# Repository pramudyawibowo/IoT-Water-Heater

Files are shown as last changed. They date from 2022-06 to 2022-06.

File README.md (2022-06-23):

## Project IoT : 
# Pemanas Air Otomatis dengan Monitoring Suhu dan Kelembapan Udara

## Anggota Kelompok 
| No | Nama | NIM |
|:--:|:---:|:---:|
|  1 | Abdur Rozak Junaidi | 1941720094 |
|  2 | Dwi Nur Oktaviani | 1941720239 |
|  3 | Pramudya Wibowo | 1941720054 |

## Pengkabelan
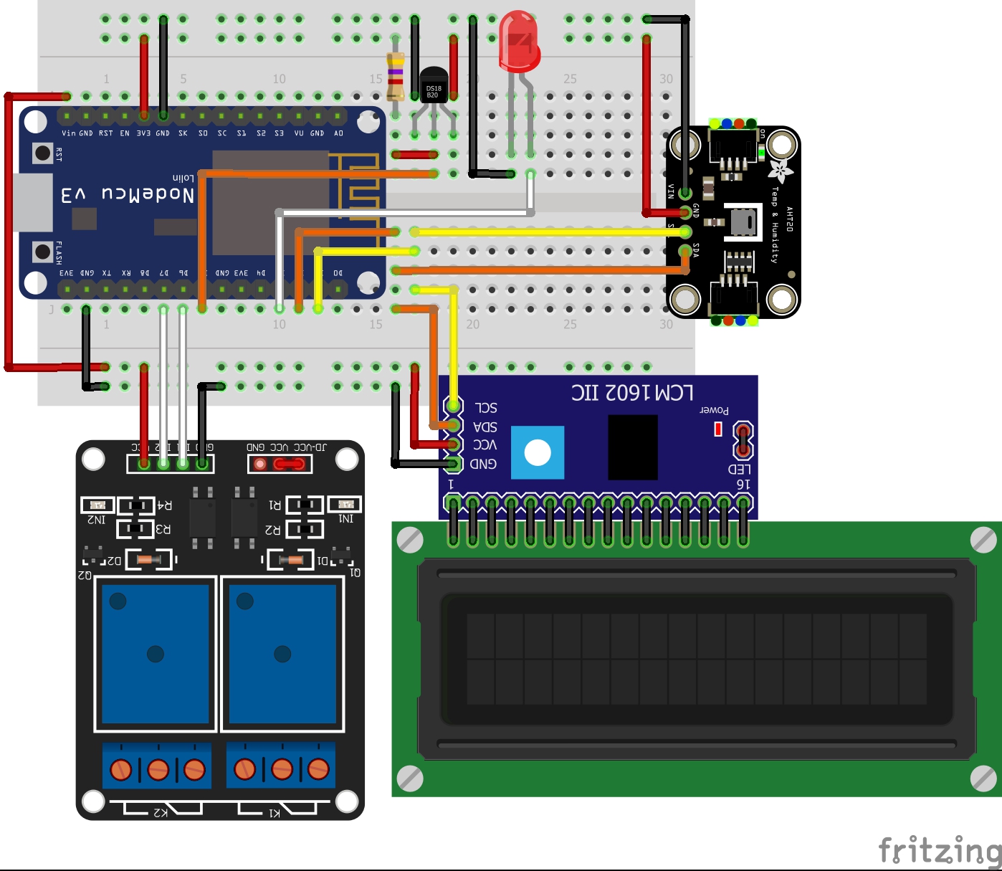
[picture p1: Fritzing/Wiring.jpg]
Pengkabelan Fritzing
 

## Langkah Penggunaan Kode Program
* Atur pengkabelan seperti pada contoh diatas
* Ubah SSID dan Password dengan SSID dan Password dari Wifi yang digunakan.
* Atur alamat MQTT Broker yang digunakan.
* Atur pin-pin dari perangkat apabila diperlukan.
* Upload program, tunggu perangkat booting hingga LCD menunjukkan tampilan monitoring suhu.
* Akses node-red dashboard dengan alamat http://168.138.175.53:1880/ui
* Demo project dan uji coba dapat dilihat melalui link berikut https://youtu.be/ZZKoxPK8TpI

Demo Project IoT (https://youtu.be/ZZKoxPK8TpI "Demo Project IoT")

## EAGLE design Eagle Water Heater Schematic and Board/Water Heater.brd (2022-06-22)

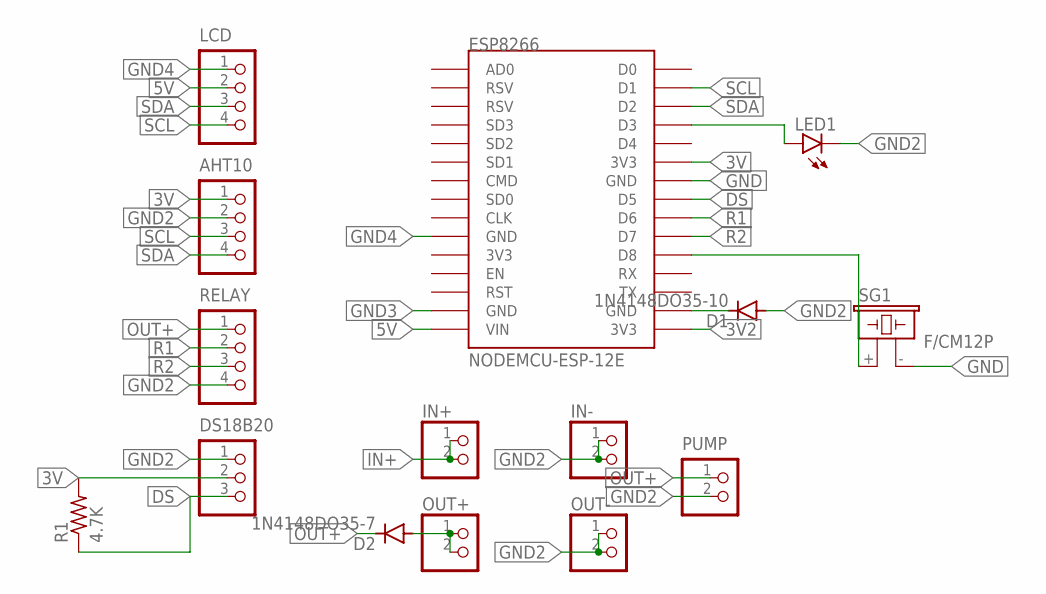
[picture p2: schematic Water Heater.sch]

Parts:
AHT10: B4B-XH-A
D1: 1N4148DO35-10; DO35-10
D2: 1N4148DO35-7; DO35-7
DS18B20: B3B-XH-A
ESP8266: NODEMCU-ESP-12E
IN+: PINHD-1X2; 1X02
IN-: PINHD-1X2; 1X02
LCD: B4B-XH-A
LED1: LED3MM
OUT+: PINHD-1X2; 1X02
OUT-: PINHD-1X2; 1X02
PUMP: B2B-XH-A
R1: 4.7K; 0204/7
RELAY: B4B-XH-A
SG1: F/CM12P

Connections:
3V: AHT10.1, DS18B20.2, ESP8266.3V3@1 (3V3), R1.2
3V2: ESP8266.3V3@2 (3V3)
5V: ESP8266.VIN, LCD.2
DS: DS18B20.3, ESP8266.D5, R1.1
GND: ESP8266.GND@2 (GND), SG1.- (2)
GND2: AHT10.2, D1.A, DS18B20.1, IN-.1, IN-.2, LED1.K (C), OUT-.1, OUT-.2, PUMP.2, RELAY.4
GND3: ESP8266.GND@1 (GND)
GND4: ESP8266.GND@0 (GND), LCD.1
IN+: IN+.1, IN+.2
unnamed: ESP8266.D3, LED1.A
unnamed: ESP8266.D8, SG1.+ (1)
unnamed: D1.C, ESP8266.GND@3 (GND)
unnamed: D2.A, OUT+.1, OUT+.2
OUT+: D2.C, PUMP.1, RELAY.1
R1: ESP8266.D6, RELAY.2
R2: ESP8266.D7, RELAY.3
SCL: AHT10.3, ESP8266.D1, LCD.4
SDA: AHT10.4, ESP8266.D2, LCD.3

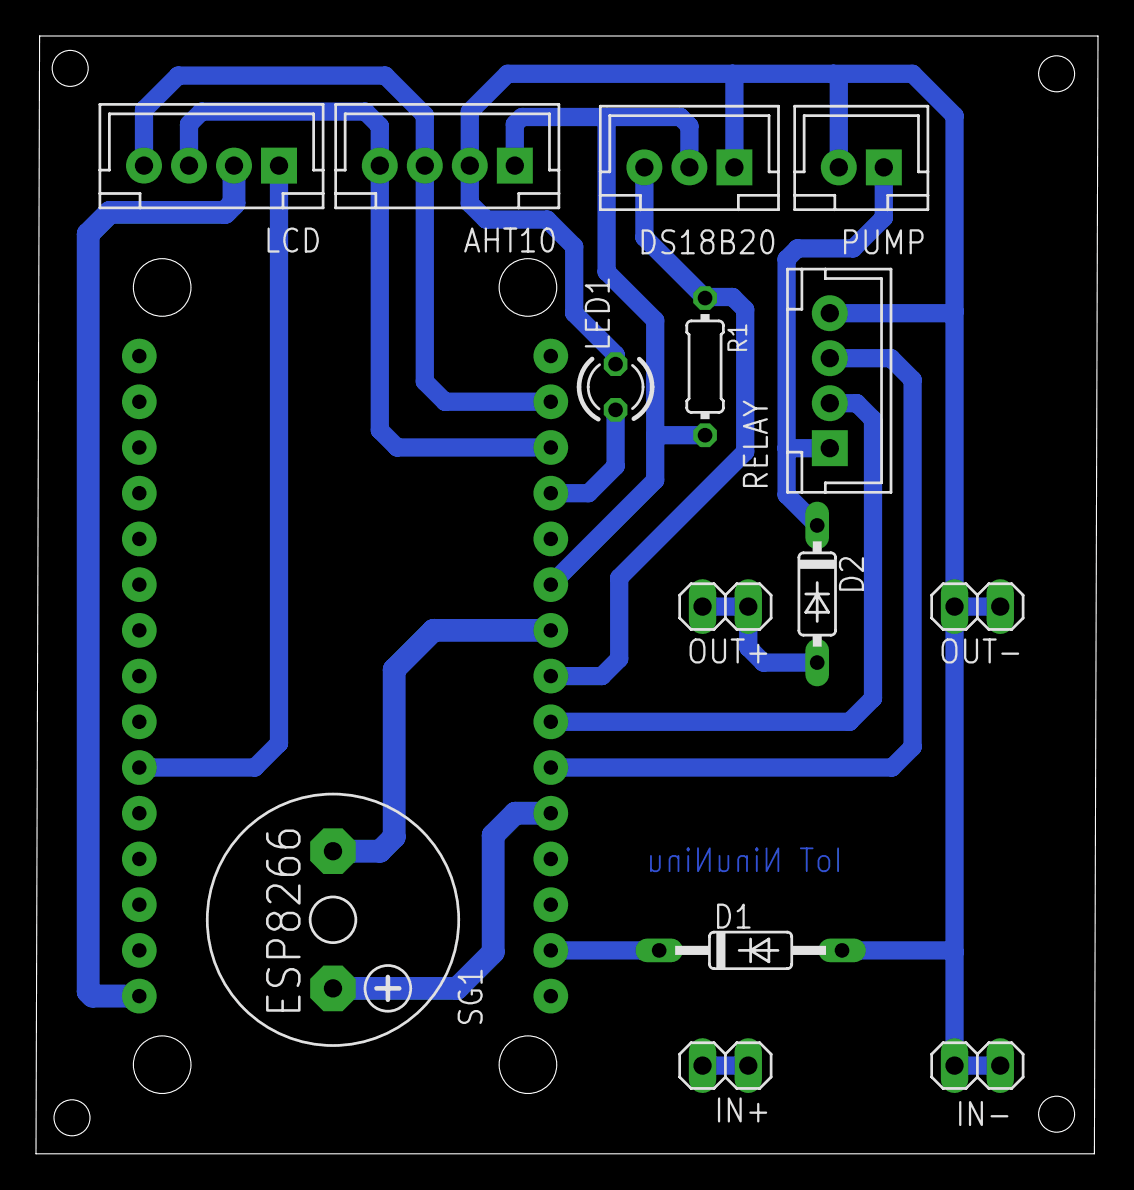
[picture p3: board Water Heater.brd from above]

Board: 2 copper layers, 59.0 x 62.1 mm, 15 parts (0 on the bottom side), 16 nets.

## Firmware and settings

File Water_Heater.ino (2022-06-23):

#include <Arduino.h>
#include <ESP8266WiFi.h>
#include <PubSubClient.h>
#include <Adafruit_AHT10.h>
#include <LiquidCrystal_I2C.h>
#include <OneWire.h>
#include <DallasTemperature.h>
#include <EEPROM.h>

#define pinDS     D5
#define pinPompa  D7
#define pinHeater D6
#define pinLED    D3
#define pinBuzzer D8

const char *ssid = "SSID";
const char *password = "password";
const char *mqtt_server = "138.2.87.224";
String newHostname = "water-heater";
WiFiClient espClient;
PubSubClient client(espClient);
Adafruit_AHT10 aht;
LiquidCrystal_I2C lcd(0x27, 16, 2);
OneWire DS18B20(pinDS);
DallasTemperature ds(&DS18B20);
char buff[33];
unsigned long previousSend = 0, previousSensor = 0, previousPompa = 0, previousBuzzer = 0;
byte heaterChar[] = {0x0E, 0x0A, 0x0A, 0x0E, 0x1F, 0x1F, 0x1F, 0x0E};
byte powerChar[] = {0x00, 0x04, 0x04, 0x0E, 0x15, 0x11, 0x11, 0x0E};

float suhuUdara, kelembapanUdara, suhuUdaraMax, suhuAir, suhuAirMin;
sensors_event_t humidity, temp;
bool heater = false, pompa = false, buzzer = false;
String heaterStatus = "false";
int seconds = 1, buzzerCount = 0;

void initInterface() {
  lcd.init();
  lcd.backlight();
  lcd.createChar(1, powerChar);
  lcd.createChar(2, heaterChar);
}

void printLcd(int col, int row, String text) {
  lcd.setCursor(col, row);
  lcd.print(text);
}

void initDevices() {
  pinMode(pinLED, OUTPUT);
  pinMode(pinHeater, OUTPUT);
  pinMode(pinPompa, OUTPUT);
  pinMode(pinBuzzer, OUTPUT);
  digitalWrite(pinLED, LOW);
  digitalWrite(pinHeater, HIGH);
  digitalWrite(pinPompa, HIGH);
  aht.begin();
  ds.begin();
}

void readSensors() {
  unsigned long currentSensor = millis();
  if (currentSensor - previousSensor >= 500) {
    previousSensor = currentSensor;
    aht.getEvent(&humidity, &temp);
    kelembapanUdara = humidity.relative_humidity;
    suhuUdara = temp.temperature;
    ds.setResolution(12);
    ds.requestTemperatures();
    suhuAir = ds.getTempCByIndex(0);
  }
}

void initWifi() {
  WiFi.mode(WIFI_STA);
  WiFi.hostname(newHostname.c_str());
  WiFi.begin(ssid, password);
  printLcd(0, 0, "   CONNECTING   ");
  while (WiFi.status() != WL_CONNECTED) {
    delay(250);
  }
  printLcd(0, 0, "   CONNECTED!   ");
  printLcd(0, 1, "IP:");
  printLcd(3, 1, WiFi.localIP().toString());
  delay(2000);
  lcd.clear();
}

void initMqtt() {
  client.setServer(mqtt_server, 1883);
  client.setCallback(callback);
}

void reconnect() {
  while (!client.connected()) {
    printLcd(0, 0, "Connecting MQTT ");
    delay(500);
    if (client.connect("WaterHeater")) {
      printLcd(0, 0, " MQTT Connected ");
      client.subscribe("heater/status");
      client.subscribe("heater/suhuHeater");
      client.subscribe("heater/saveHeater");
      client.subscribe("heater/suhuUdara");
      client.subscribe("heater/saveUdara");
      client.subscribe("pompa/status");
    } else {
      printLcd(0, 0, "MQTT Failed    ");
      printLcd(0, 1, String(client.state()));
    }
  }
  delay(500);
}

void callback(char* topic, byte* message, unsigned int length) {
  String messageTemp;
  for (int i = 0; i < length; i++) {
    messageTemp += (char)message[i];
  }
  if (String(topic) == "heater/status") {
    if (messageTemp == "false") {
      heater = false;
    } else if (messageTemp == "true") {
      heater = true;
    }
  }
  if (String(topic) == "heater/suhuHeater") {
    suhuAirMin = messageTemp.toFloat();
  }
  if (String(topic) == "heater/saveHeater") {
    if (messageTemp == "true") {
      printLcd(6, 1, " OK ");
      delay(500);
      EEPROM_writeFloat(0, suhuAirMin);
    }

  }
  if (String(topic) == "heater/suhuUdara") {
    suhuUdaraMax = messageTemp.toFloat();
  }
  if (String(topic) == "heater/saveUdara") {
    if (messageTemp == "true") {
      printLcd(12, 1, " OK ");
      delay(500);
      EEPROM_writeFloat(4, suhuUdaraMax);
    }
  }
  if (String(topic) == "pompa/status") {
    if (messageTemp == "false") {
      pompa = false;
    } else if (messageTemp == "true") {
      pompa = true;
      seconds = 1;
    }
  }
}

void readVariables() {
  EEPROM.begin(8);
  suhuAirMin = EEPROM_readFloat(0);
  suhuUdaraMax = EEPROM_readFloat(4);
}


void setup() {
  // put your setup code here, to run once:
  readVariables();
  initInterface();
  initDevices();
  initWifi();
  initMqtt();
  lcd.clear();
}

void loop() {
  // put your main code here, to run repeatedly:
  if (!client.connected()) {
    reconnect();
    lcd.clear();
  }
  if (!client.loop()) {
    client.connect("WaterHeater");
  }

  readSensors();
  lcd.setCursor(5, 0); lcd.write(2);
  dtostrf(suhuAir, 2, 1, buff);
  printLcd(6, 0, buff);
  lcd.setCursor(10, 0); lcd.print(" *");
  dtostrf(suhuUdara, 2, 1, buff);
  printLcd(12, 0, buff);
  dtostrf(suhuAirMin, 2, 1, buff);
  printLcd(6, 1, buff);
  dtostrf(suhuUdaraMax, 2, 1, buff);
  printLcd(12, 1, buff);

  lcd.setCursor(0, 0); lcd.write(1);
  if (heater) {
    printLcd(1, 0, "ON ");
    heaterStatus = "true";
    if (suhuUdara < suhuUdaraMax) {
      if (suhuAir < suhuAirMin - 2.0) {
        digitalWrite(pinHeater, LOW);
        digitalWrite(pinLED, HIGH);
      } else {
        if (suhuAir == suhuAirMin - 2.0) buzzer = true;
        digitalWrite(pinHeater, HIGH);
        digitalWrite(pinLED, LOW);
      }
    } else {
      digitalWrite(pinHeater, HIGH);
      digitalWrite(pinLED, LOW);
    }
  } else {
    printLcd(1, 0, "OFF");
    heaterStatus = "false";
    digitalWrite(pinHeater, HIGH);
    digitalWrite(pinLED, LOW);
  }

  if (pompa) {
    digitalWrite(pinPompa, LOW);
    unsigned long currentPompa = millis();
    if (seconds == 30) {
      pompa = false;
      seconds = 0;
    }
    if (currentPompa - previousPompa >= 1000) {
      previousPompa = currentPompa;
      seconds++;
      buzzer = true;
    }
  } else {
    digitalWrite(pinPompa, HIGH);
  }

  if (buzzer && buzzerCount < 3) {
    unsigned long currentBuzzer = millis();
    if (currentBuzzer - previousBuzzer >= 250) {
      previousBuzzer = currentBuzzer;
      tone(pinBuzzer, 1500, 200);
      buzzerCount++;
    }
  } else {
    buzzer = false;
    buzzerCount = 0;
  }

  unsigned long currentSend = millis();
  if (currentSend - previousSend >= 1000) {
    previousSend = currentSend;
    char tempSuhu[8];
    dtostrf(suhuUdara, 1, 2, tempSuhu);
    client.publish("udara/suhu", tempSuhu);

    char tempHumidity[8];
    dtostrf(kelembapanUdara, 1, 2, tempHumidity);
    client.publish("udara/kelembapan", tempHumidity);

    char tempHeater[8];
    dtostrf(suhuAir, 1, 2, tempHeater);
    client.publish("heater/suhu", tempHeater);

    char tempHeaterStatus[8];
    heaterStatus.toCharArray(tempHeaterStatus, 8);
    client.publish("heater/statusIn", tempHeaterStatus);
  }
}

void EEPROM_writeFloat(int ee, float value) {
  byte* p = (byte*)(void*)&value;
  for (int i = 0; i < 4; i++) {
    EEPROM.write(ee++, *p++);
    EEPROM.commit();
  }
}

float EEPROM_readFloat(int ee) {
  float value = 0.0;
  byte* p = (byte*)(void*)&value;
  for (int i = 0; i < 4; i++) {
    *p++ = EEPROM.read(ee++);
  }
  return value;
}

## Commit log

2022-06-22 Menambahkan pengkabelan fritzing
    [Wiring.fzz]
2022-06-22 Menambahkan skematik dan board eagle untuk pcb
    [Water Heater.brd, Water Heater.sch]
2022-06-23 Change MQTT Broker Server IP Address
    [Water_Heater.ino]
